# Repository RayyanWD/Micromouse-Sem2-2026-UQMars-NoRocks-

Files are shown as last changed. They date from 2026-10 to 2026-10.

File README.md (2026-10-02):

# Micromouse-Sem2-2026-UQMars-NoRocks-

# NO ROCKS ? – UQ Micromouse 2026

An autonomous micromouse built for the UQ Micromouse competition (4 October 2026).
It explores a 9×9 maze using a flood-fill algorithm, maps the walls as it goes,
and uses that saved map for faster runs to the centre.

**Team:** Rayyan Dewangga and Gordon Tam

**Video:** [YouTube / Google Drive link]
**Design document:** [docs/Design_Document.pdf](docs/Design_Document.pdf)
**Budget:** $180.17 AUD of $1,500 – see [docs/Micromouse_Budget.xlsx](docs/Micromouse_Budget.xlsx)

---

## Hardware

| Part | Purpose |
|---|---|
| ESP32-32U dev board | Main controller |
| 2× N20 motors with encoders (30:1, 7 PPR) | Drive + distance measurement |
| Pololu 32 mm wheels | Traction |
| DFRobot TB6612FNG motor driver (DRI0044) | Drives both motors |
| 3× VL53L0X time-of-flight sensors | Front, left and right wall detection |
| TCS34725 colour sensor | Floor / tile detection |
| MPU-6500 gyro | Mounted for future turn correction |
| MP1584EN buck converter | Battery → 3.3 V logic supply |
| 6×AA battery pack + rocker switch | Power |
| 3D-printed PLA chassis | Single flat deck, under 16 × 16 × 8 cm |

## Wiring summary

| Connection | ESP32 pin |
|---|---|
| Left motor PWM / DIR | GPIO 25 / 26 |
| Right motor PWM / DIR | GPIO 27 / 13 |
| Left encoder A / B | GPIO 34 / 35 |
| Right encoder A / B | GPIO 36 (VP) / 39 (VN) |
| ToF sensors SDA / SCL (I2C bus 1) | GPIO 21 / 22 |
| ToF XSHUT front / left / right | GPIO 16 / 17 / 18 |
| Colour sensor SDA / SCL (I2C bus 2) | GPIO 32 / 33 |
| Start / mode button | GPIO 0 (on-board BOOT) |
| Status LED | GPIO 2 (on-board) |

Power: battery → switch → motor driver VM and buck converter IN+.
Buck converter OUT+ (3.3 V) → ESP32 3V3, driver VCC, all sensors and encoders.
All grounds are common. Full diagram: [electronics/wiring.png](electronics/wiring.png)

## Software

`code/micromouse/micromouse.ino` – a single Arduino sketch for the ESP32.

- **Flood-fill search:** at every cell the mouse reads its walls, updates the map,
  recomputes distances to the centre and moves to the lowest-distance neighbour.
- **Map saved to flash**, so later runs use the known map for faster, straighter paths.
- **Wall centring** using the side ToF sensors, with encoder-based straight-line
  correction where there are no walls.
- **Colour sensor** reads the floor and can optionally treat a marked tile as the goal.

### Modes (BOOT button: short press = next mode, hold ~1 s = start)
The blue LED blinks the mode number.

1. **Explore** – flood-fill search to the centre, then back to start
2. **Speed run** – fastest known path using the saved map
3. **Sensors** – live ToF, colour and encoder readings over Serial (calibration)
4. **Test** – motor direction check, one cell straight, four 90° turns (calibration)
5. **Clear map** – wipe the saved maze

## Building and uploading

1. Install [Arduino IDE](https://www.arduino.cc/en/software) and the **esp32** board package.
2. Install the libraries **VL53L0X** (Pololu) and **Adafruit TCS34725** from Library Manager.
3. Open `code/micromouse/micromouse.ino`, select **ESP32 Dev Module**, and upload.
4. Open Serial Monitor at **115200 baud** to see sensor status and debug output.

Calibration values (wheel size, turn scale, wall thresholds, motor speeds)
are all in the `CALIBRATION` section at the top of the sketch.

## Repository structure

```
code/           Arduino source
docs/           Design document, budget spreadsheet, receipts
cad/            Chassis STL/STEP files
electronics/    Wiring diagram
media/          Photos and video link
```

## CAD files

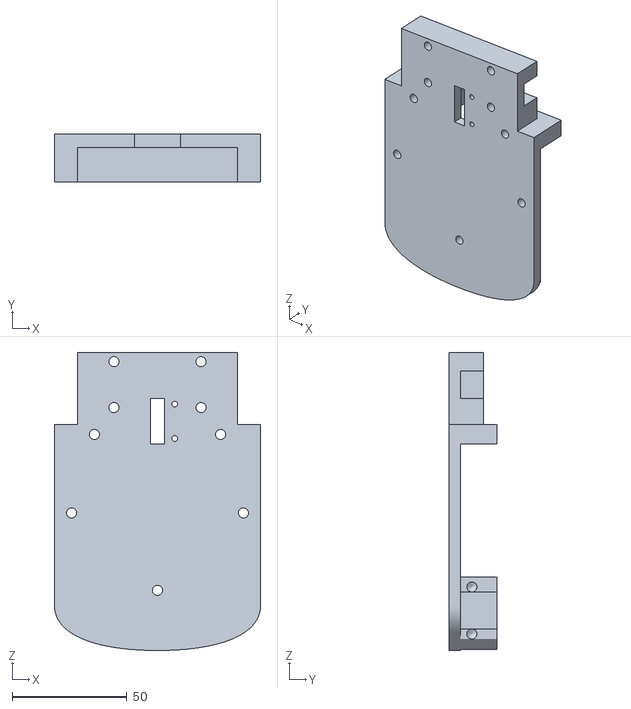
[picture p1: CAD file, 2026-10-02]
CAD/Base.stl
90.0 x 21.0 x 130.0

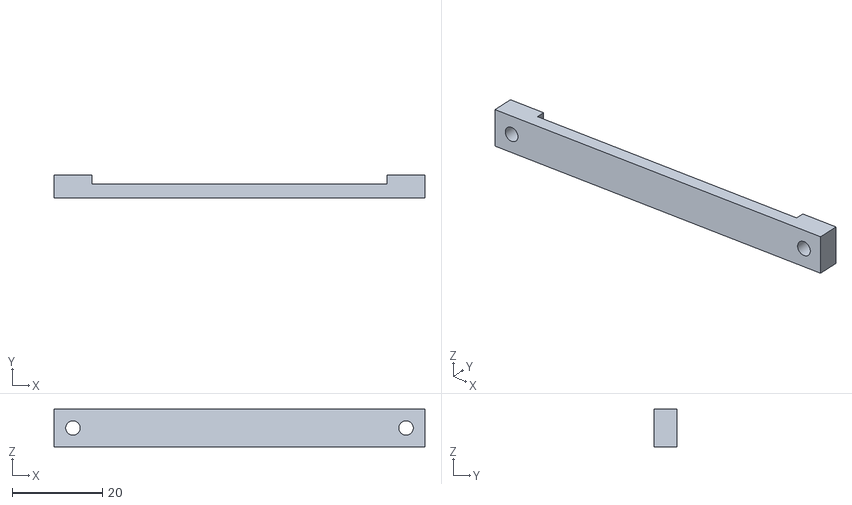
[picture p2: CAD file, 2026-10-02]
CAD/Clamp Strip.stl
82.4 x 5.00 x 8.40

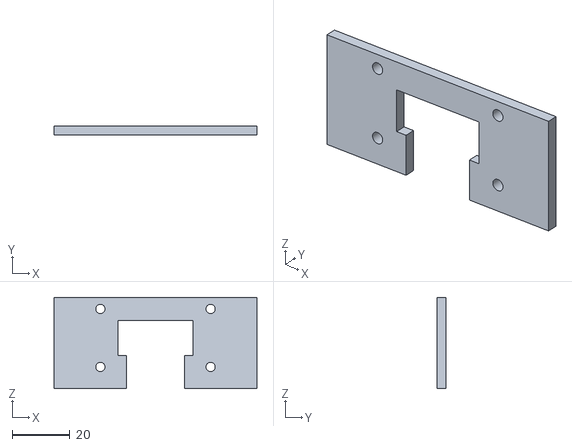
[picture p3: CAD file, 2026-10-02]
CAD/Top Deck.stl
70.0 x 3.00 x 31.5

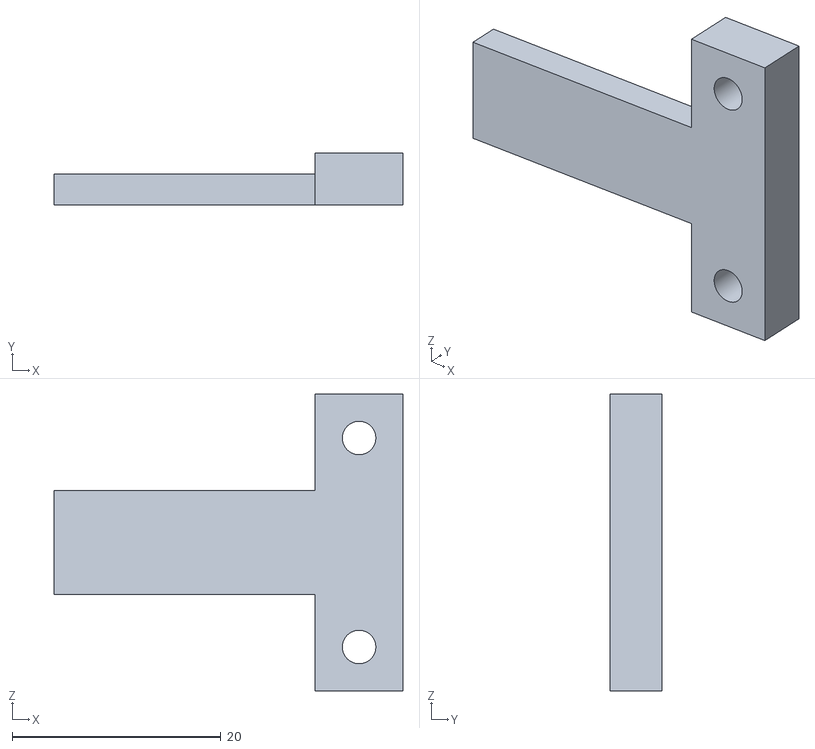
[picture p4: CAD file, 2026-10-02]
CAD/Small Clap.stl
33.4 x 5.00 x 28.4

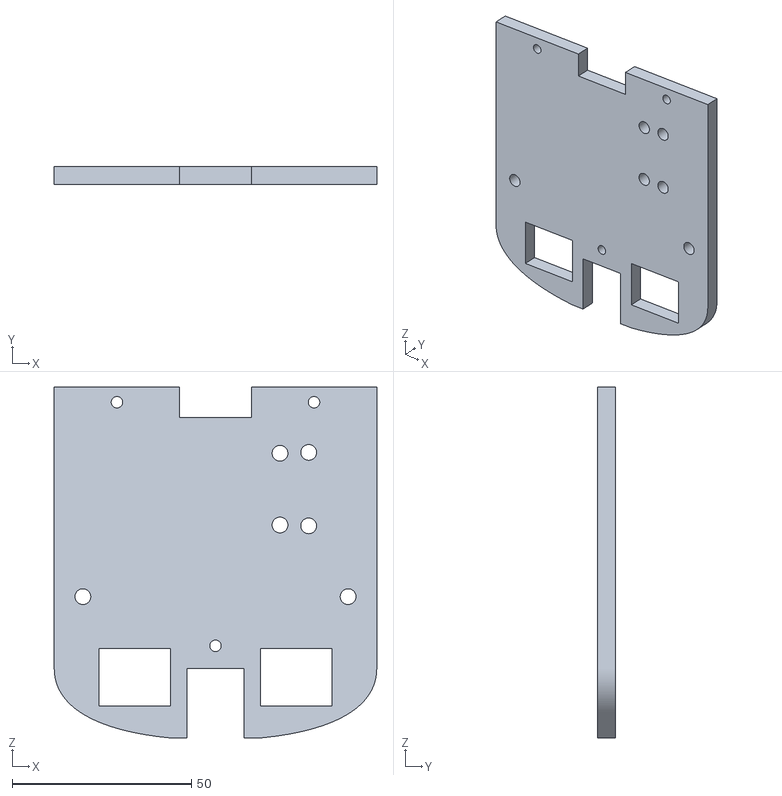
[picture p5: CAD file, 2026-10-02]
CAD/Mount Plate.stl
90.0 x 5.00 x 97.9

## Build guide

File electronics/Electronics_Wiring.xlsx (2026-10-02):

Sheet: Connections
No Rocks – wiring list (every connection)
From part | From pin | Wire colour | To part | To pin | Net | Notes
6×AA battery tray | + (red) | Red | Rocker switch | Terminal 1 | VBAT | Before switch
Rocker switch | Terminal 2 | Red | Splitter → TB6612FNG | VM (+12V) | VBAT | Battery voltage – never on VCC
Rocker switch | Terminal 2 | Red | Splitter → MP1584EN buck | IN+ | VBAT
6×AA battery tray | − (black) | Black | Ground harness (tail) | — | GND
MP1584EN buck | IN− | Black | Ground harness | — | GND | Two legs used, either is fine
MP1584EN buck | OUT− | Black | Ground harness | — | GND | Same ground as IN− on MP1584
MP1584EN buck | OUT+ (pin 1) | Red | 3.3 V splitter A (tail) | — | 3V3 | Set buck to 3.3–3.45 V before connecting
MP1584EN buck | OUT+ (pin 2) | Red | 3.3 V splitter B (tail) | — | 3V3
3.3 V splitter A | Leg | Red | ESP32 | 3V3 | 3V3
3.3 V splitter A | Leg | Red | TB6612FNG | VCC | 3V3 | Logic supply
3.3 V splitter A | Leg | Yellow | Left N20 motor | Yellow (enc VCC) | 3V3
3.3 V splitter A | Leg | Yellow | Right N20 motor | Yellow (enc VCC) | 3V3
3.3 V splitter B | Leg | Red | VL53L0X front | VIN | 3V3
3.3 V splitter B | Leg | Red | VL53L0X left | VIN | 3V3
3.3 V splitter B | Leg | Red | VL53L0X right | VIN | 3V3
3.3 V splitter B | Leg | Red | TCS34725 colour | VIN | 3V3
3.3 V splitter B | Leg | Red | MPU-6500 gyro | VCC | 3V3 | Optional
Ground harness | Leg | Black | ESP32 | GND (×2 pins) | GND | One per harness
Ground harness | Leg | Black | TB6612FNG | GND (×2) | GND
Ground harness | Leg | Blue | Left N20 motor | Blue (GND) | GND
Ground harness | Leg | Blue | Right N20 motor | Blue (GND) | GND
Ground harness | Leg | Black | VL53L0X front / left / right | GND | GND
Ground harness | Leg | Black | TCS34725 colour | GND | GND
Ground harness | Leg | Black | MPU-6500 gyro | GND | GND
ESP32 | GPIO25 | Signal | TB6612FNG | PWM1 | PWM_L | Left motor speed
ESP32 | GPIO26 | Signal | TB6612FNG | DIR1 | DIR_L | Left motor direction
ESP32 | GPIO27 | Signal | TB6612FNG | PWM2 | PWM_R | Right motor speed
ESP32 | GPIO13 | Signal | TB6612FNG | DIR2 | DIR_R | Right motor direction
TB6612FNG | M1+ | Red | Left N20 motor | Red (M+) | ML+
TB6612FNG | M1− | Black | Left N20 motor | Black (M−) | ML- | Not ground
TB6612FNG | M2+ | Red | Right N20 motor | Red (M+) | MR+
TB6612FNG | M2− | Black | Right N20 motor | Black (M−) | MR- | Not ground
Left N20 motor | Green (enc A) | Green | ESP32 | GPIO34 | ENC_LA | Input-only pin
Left N20 motor | White (enc B) | White | ESP32 | GPIO35 | ENC_LB | Input-only pin
Right N20 motor | Green (enc A) | Green | ESP32 | GPIO36 (VP) | ENC_RA | Input-only pin
Right N20 motor | White (enc B) | White | ESP32 | GPIO39 (VN) | ENC_RB | Input-only pin
I2C SDA splitter (blue) | Tail | Blue | ESP32 | GPIO21 | SDA1
I2C SDA splitter (blue) | Legs | Blue | VL53L0X ×3 + MPU-6500 | SDA / SDA/SDI | SDA1
I2C SCL splitter (brown) | Tail | Brown | ESP32 | GPIO22 | SCL1
I2C SCL splitter (brown) | Legs | Brown | VL53L0X ×3 + MPU-6500 | SCL / SCL/SCLK | SCL1
ESP32 | GPIO16 | Signal | VL53L0X front | XSHUT | XSHUT_F | Code sets address 0x30
ESP32 | GPIO17 | Signal | VL53L0X left | XSHUT | XSHUT_L | Code sets address 0x31
ESP32 | GPIO18 | Signal | VL53L0X right | XSHUT | XSHUT_R | Code sets address 0x32
ESP32 | GPIO32 | Signal | TCS34725 colour | SDA | SDA2 | Own I2C bus (Wire1)
ESP32 | GPIO33 | Signal | TCS34725 colour | SCL | SCL2 | Own I2C bus (Wire1)
TCS34725 colour | LED / INT / 3V3 out | — | Not connected | — | NC | LED left on

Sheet: ESP32 pins
No Rocks – ESP32 pin map (matches micromouse.ino)
ESP32 pin | Function | Net | Connected to | Name in code | Notes
3V3 | Power in | 3V3 | Buck OUT+ via splitter A
GND | Ground | GND | Ground harness (×2)
GPIO25 | PWM out | PWM_L | TB6612FNG PWM1 | L_PWM
GPIO26 | Digital out | DIR_L | TB6612FNG DIR1 | L_DIR
GPIO27 | PWM out | PWM_R | TB6612FNG PWM2 | R_PWM
GPIO13 | Digital out | DIR_R | TB6612FNG DIR2 | R_DIR
GPIO34 | Input (interrupt) | ENC_LA | Left motor green | L_ENC_A | Input-only, no pull-up
GPIO35 | Input | ENC_LB | Left motor white | L_ENC_B | Input-only, no pull-up
GPIO36 (VP) | Input (interrupt) | ENC_RA | Right motor green | R_ENC_A | Input-only, no pull-up
GPIO39 (VN) | Input | ENC_RB | Right motor white | R_ENC_B | Input-only, no pull-up
GPIO21 | I2C SDA (bus 1) | SDA1 | 3× VL53L0X, MPU-6500 | I2C1_SDA
GPIO22 | I2C SCL (bus 1) | SCL1 | 3× VL53L0X, MPU-6500 | I2C1_SCL
GPIO16 | Digital out | XSHUT_F | Front ToF XSHUT | XSHUT_F
GPIO17 | Digital out | XSHUT_L | Left ToF XSHUT | XSHUT_L
GPIO18 | Digital out | XSHUT_R | Right ToF XSHUT | XSHUT_R
GPIO32 | I2C SDA (bus 2) | SDA2 | TCS34725 | I2C2_SDA
GPIO33 | I2C SCL (bus 2) | SCL2 | TCS34725 | I2C2_SCL
GPIO0 | Input (pull-up) | — | On-board BOOT button | BTN_PIN | Short press = next mode, hold = start
GPIO2 | Digital out | — | On-board blue LED | LED_PIN | Blinks mode number

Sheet: Power
No Rocks – power rails
Rail | Voltage | Feeds
6×AA battery | 7.2 V (NiMH) – 9 V (alkaline) | Rocker switch → VBAT
VBAT | Battery voltage | TB6612FNG VM (motor power, max 12 V), MP1584EN IN+
MP1584EN OUT+ | Measured 3.45 V (lowest setting reached) | ESP32 3V3, TB6612 VCC, ToF ×3, colour sensor, gyro, encoders
GND | Common | Every part shares one ground

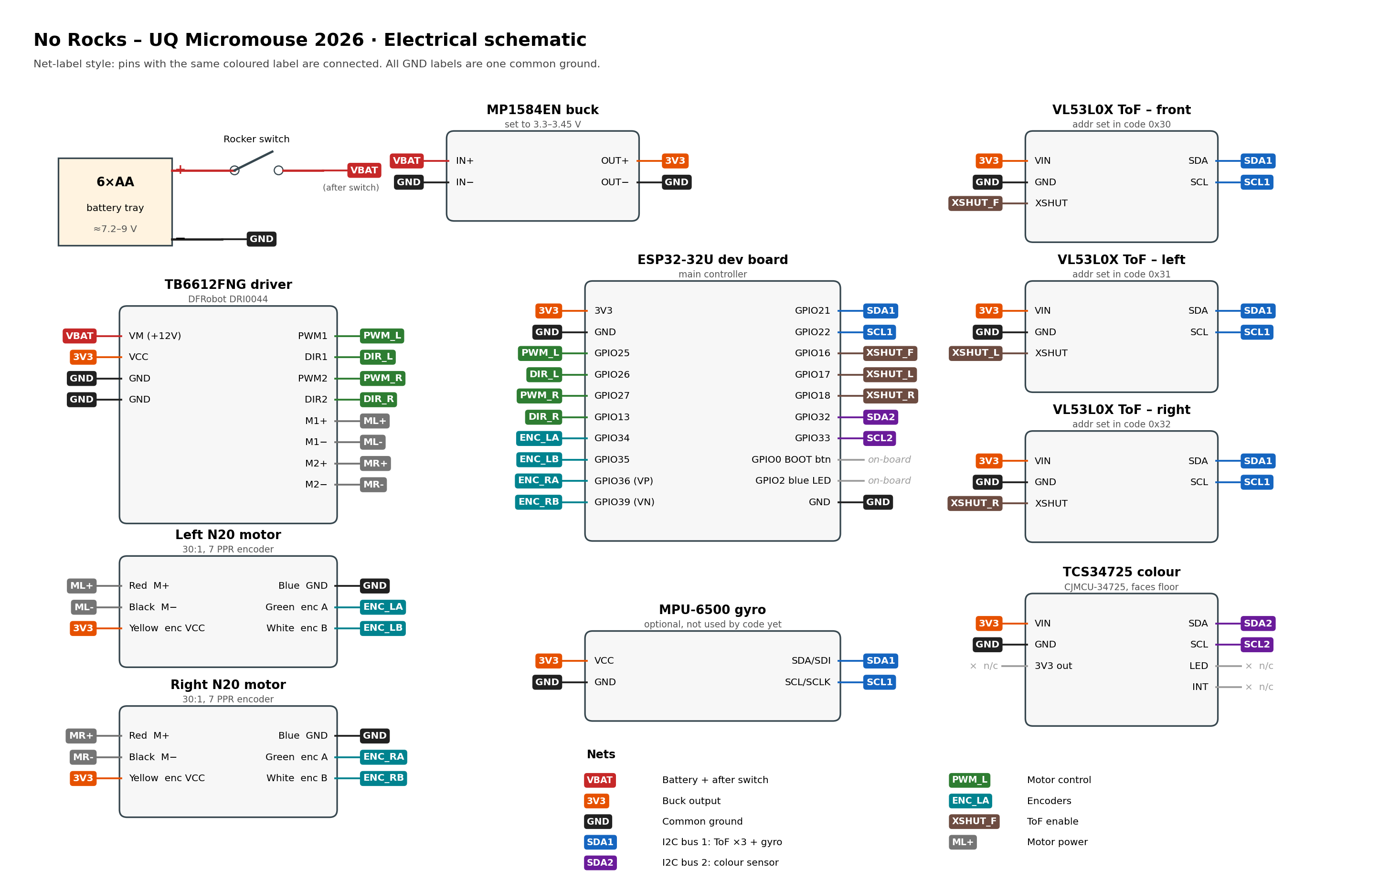
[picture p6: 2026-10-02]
electronics/wiring.png

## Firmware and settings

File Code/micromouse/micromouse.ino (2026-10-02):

/*
  UQ Micromouse 2026 – ESP32 firmware
  -----------------------------------
  Hardware (matches the wiring list):
    Motor driver  DIR/PWM type (pins VCC GND DIR2 PWM2 PWM1 DIR1)
                  PWM1 25, DIR1 26 (left)   PWM2 27, DIR2 13 (right)
    Encoders      left A/B 34/35          right A/B 36/39
    I2C bus 1     SDA 21, SCL 22  -> 3x VL53L0X
    VL53L0X XSHUT front 16, left 17, right 18
    I2C bus 2     SDA 32, SCL 33  -> colour sensor (TCS34725)
    Button        GPIO 0 (the BOOT button on the ESP32 board)
    Status LED    GPIO 2 (the blue LED on the ESP32 board)

  Libraries (Arduino IDE > Library Manager):
    - "VL53L0X" by Pololu
    - "Adafruit TCS34725"
  Board: "ESP32 Dev Module" (esp32 core 2.x or 3.x both work)

  No display: status goes to the blue LED and to Serial Monitor (115200 baud).
    LED blinks the mode number: 1 = Explore, 2 = Speed run, 3 = Sensors,
    4 = Test, 5 = Clear map. Solid on = running. Fast flicker = goal reached.

  Using it:
    Short press BOOT = next mode, long press (hold ~1 s, then release) = start.
    Modes:
      Explore   – flood-fill search to the centre, maps as it goes, saves map
      Speed run – uses the saved map for the fastest known path
      Sensors   – live ToF / colour / encoder readings (for calibration)
      Test      – checks motor direction, 1 cell straight, 4 right turns
      Clear map – wipe the saved map (do this once the real maze is revealed!)
    Press BOOT during any run to abort.

  Calibration values are all in the CALIBRATION section below. Changing those
  between runs is calibration, not a change to the navigation algorithm.
*/

#include <Wire.h>
#include <VL53L0X.h>
#include <Adafruit_TCS34725.h>
#include <Preferences.h>

#ifndef ESP_ARDUINO_VERSION_MAJOR
#define ESP_ARDUINO_VERSION_MAJOR 2
#endif

// ======================= PINS =======================
#define L_PWM    25   // driver PWM1
#define L_DIR    26   // driver DIR1
#define R_PWM    27   // driver PWM2
#define R_DIR    13   // driver DIR2
#define L_ENC_A  34
#define L_ENC_B  35
#define R_ENC_A  36
#define R_ENC_B  39
#define XSHUT_F  16
#define XSHUT_L  17
#define XSHUT_R  18
#define I2C1_SDA 21
#define I2C1_SCL 22
#define I2C2_SDA 32
#define I2C2_SCL 33
#define BTN_PIN  0
#define LED_PIN  2

// ======================= CALIBRATION =======================
// Set to 0 if your motors have no encoders (falls back to timed moves).
#define USE_ENCODERS 1

// Motors: BJ-N20-12-1000 (12 V, 1:30 gearbox, 7 PPR encoder)
//   Blue=GND  Green=Enc A  White=Enc B  Yellow=3.3V  Black=Motor-  Red=Motor+
const float WHEEL_DIA_MM         = 32.0;   // 32 mm wheels with silicone tyres
const float COUNTS_PER_WHEEL_REV = 420.0;  // 7 pulses x 2 edges x 30:1 gearbox
const float TRACK_MM             = 90.0;   // MEASURE: distance between the two wheel centres
const float TURN_SCALE           = 1.00;   // >1 if turns come up short, <1 if they overshoot
const float CELL_MM              = 180.0;

// Flip to -1 if a wheel spins the wrong way / an encoder counts backwards
const int L_MOTOR_DIR = 1,  R_MOTOR_DIR = 1;
const int L_ENC_DIR   = 1,  R_ENC_DIR   = 1;

// Timed fallback (only used when USE_ENCODERS is 0)
const int MS_PER_CELL = 900;   // at EXPLORE_PWM
const int MS_PER_90   = 350;   // at TURN_PWM

// Motor power (0-255). The N20s are 12 V motors on a 6-9 V pack, so full PWM is safe.
const int PWM_FREQ    = 10000;
const int MAX_PWM     = 255;
const int MIN_PWM     = 80;    // lowest value that still moves the mouse
const int EXPLORE_PWM = 150;
const int SPEED_PWM   = 210;
const int TURN_PWM    = 130;

// Wall sensing (mm, as read by each ToF). Use Sensors mode to measure.
const int FRONT_WALL_MM    = 120; // closer than this = wall ahead
const int FRONT_CENTRED_MM = 35;  // front reading when centred in a cell facing a wall
const int SIDE_WALL_MM     = 110; // closer than this = wall at the side
const int SIDE_CENTRED_MM  = 40;  // side reading when centred in a cell
const int TOF_OFFSET_F = 0, TOF_OFFSET_L = 0, TOF_OFFSET_R = 0;

// Steering gains
const float K_WALL = 1.2;  // centring between walls
const float K_ENC  = 2.0;  // keep straight from encoders when no walls

// Colour sensor
const bool  COLOUR_GOAL   = false; // true = a coloured/bright tile also counts as the goal
const float COLOUR_FACTOR = 2.0;   // tile counts as "marked" if this many times brighter than the floor

const bool RETURN_TO_START = true; // after reaching the centre, explore back to start (maps more)

// ======================= MAZE =======================
const int N = 9;
const int GOAL_X = 4, GOAL_Y = 4;
const int DX[4] = {0, 1, 0, -1};   // 0=N 1=E 2=S 3=W
const int DY[4] = {1, 0, -1, 0};

uint8_t walls[N][N];   // bit d set = wall on side d
uint8_t known[N][N];   // bit d set = side d has been seen
uint8_t distv[N][N];
int mx = 0, my = 0, hd = 0;   // position + heading. Start = (0,0) facing N, outer walls left & behind.

// ======================= OBJECTS =======================
VL53L0X tofF, tofL, tofR;
Adafruit_TCS34725 tcs(TCS34725_INTEGRATIONTIME_24MS, TCS34725_GAIN_16X);
Preferences prefs;

int  distF = 2000, distL = 2000, distR = 2000;
bool tofOK[3] = {false, false, false};
bool colourOK = false;
uint16_t floorClear = 0;
uint16_t cr, cg, cb, cc;

volatile long rawL = 0, rawR = 0;
volatile bool aborted = false;

// ======================= PWM / MOTORS =======================
#if ESP_ARDUINO_VERSION_MAJOR < 3
int pwmChan[40];
int nextChan = 0;
#endif

void pwmInit(int pin) {
#if ESP_ARDUINO_VERSION_MAJOR >= 3
  ledcAttach(pin, PWM_FREQ, 8);
#else
  pwmChan[pin] = nextChan;
  ledcSetup(nextChan, PWM_FREQ, 8);
  ledcAttachPin(pin, nextChan);
  nextChan++;
#endif
}

void pwmOut(int pin, int duty) {
#if ESP_ARDUINO_VERSION_MAJOR >= 3
  ledcWrite(pin, duty);
#else
  ledcWrite(pwmChan[pin], duty);
#endif
}

// DIR/PWM driver: DIR pin sets direction, PWM pin sets speed
void motorRaw(int pwmPin, int dirPin, int pwm) {
  pwm = constrain(pwm, -MAX_PWM, MAX_PWM);
  digitalWrite(dirPin, pwm >= 0 ? HIGH : LOW);
  pwmOut(pwmPin, abs(pwm));
}

int lastL = 0, lastR = 0;

void setMotors(int l, int r) {
  lastL = l; lastR = r;
  motorRaw(L_PWM, L_DIR, l * L_MOTOR_DIR);
  motorRaw(R_PWM, R_DIR, r * R_MOTOR_DIR);
}

// Short reverse pulse to stop quickly, then off
void brake() {
  int l = lastL, r = lastR;
  setMotors(l > 0 ? -60 : (l < 0 ? 60 : 0), r > 0 ? -60 : (r < 0 ? 60 : 0));
  delay(25);
  setMotors(0, 0);
  delay(35);
}

// ======================= ENCODERS =======================
void IRAM_ATTR isrL() { if (digitalRead(L_ENC_A) == digitalRead(L_ENC_B)) rawL--; else rawL++; }
void IRAM_ATTR isrR() { if (digitalRead(R_ENC_A) == digitalRead(R_ENC_B)) rawR--; else rawR++; }
long encL() { return rawL * L_ENC_DIR; }
long encR() { return rawR * R_ENC_DIR; }
long encDiff() { return encL() - encR(); }
void encReset() { noInterrupts(); rawL = 0; rawR = 0; interrupts(); }
float countsPerMm() { return COUNTS_PER_WHEEL_REV / (PI * WHEEL_DIA_MM); }

// ======================= ABORT / BUTTON =======================
bool checkAbort() {
  if (!aborted && digitalRead(BTN_PIN) == LOW) { aborted = true; setMotors(0, 0); }
  return aborted;
}

// 0 = nothing, 1 = short press, 2 = long press
int readButton() {
  if (digitalRead(BTN_PIN) == HIGH) return 0;
  unsigned long t0 = millis();
  while (digitalRead(BTN_PIN) == LOW) delay(5);
  delay(30);
  return (millis() - t0 > 800) ? 2 : 1;
}

void waitRelease() { while (digitalRead(BTN_PIN) == LOW) delay(5); delay(50); }

// ======================= STATUS (Serial + LED) =======================
void show(const char* a, const char* b = "", const char* c = "", const char* d = "") {
  Serial.printf("%s | %s | %s | %s\n", a, b, c, d);
}

void led(bool on) { digitalWrite(LED_PIN, on ? HIGH : LOW); }

void blinkCount(int n) {
  for (int i = 0; i < n; i++) { led(true); delay(180); led(false); delay(180); }
}

void flicker(int ms) {
  unsigned long t0 = millis();
  while (millis() - t0 < (unsigned long)ms) { led(true); delay(50); led(false); delay(50); }
}

// ======================= TOF SENSORS =======================
bool bringUpToF(int pin, VL53L0X &s, uint8_t addr) {
  digitalWrite(pin, HIGH);
  delay(10);
  s.setTimeout(100);
  if (!s.init()) return false;
  s.setAddress(addr);
  s.setMeasurementTimingBudget(20000);
  s.startContinuous(0);
  return true;
}

void initToF() {
  tofOK[0] = bringUpToF(XSHUT_F, tofF, 0x30);
  tofOK[1] = bringUpToF(XSHUT_L, tofL, 0x31);
  tofOK[2] = bringUpToF(XSHUT_R, tofR, 0x32);
}

// Non-blocking read: returns true if a new value arrived
bool pollToF(VL53L0X &s, int &out, int offset) {
  if ((s.readReg(VL53L0X::RESULT_INTERRUPT_STATUS) & 0x07) == 0) return false;
  uint16_t r = s.readReg16Bit(VL53L0X::RESULT_RANGE_STATUS + 10);
  s.writeReg(VL53L0X::SYSTEM_INTERRUPT_CLEAR, 0x01);
  out = (r == 0 || r >= 2000) ? 2000 : (int)r + offset;
  return true;
}

void updateToF() {
  if (tofOK[0]) pollToF(tofF, distF, TOF_OFFSET_F);
  if (tofOK[1]) pollToF(tofL, distL, TOF_OFFSET_L);
  if (tofOK[2]) pollToF(tofR, distR, TOF_OFFSET_R);
}

void settleToF(int ms) {
  unsigned long t0 = millis();
  while (millis() - t0 < (unsigned long)ms) { updateToF(); delay(3); }
}

// ======================= COLOUR SENSOR =======================
void readColour() { if (colourOK) tcs.getRawData(&cr, &cg, &cb, &cc); }

void calibrateFloor() {
  if (!colourOK) return;
  uint32_t sum = 0;
  for (int i = 0; i < 4; i++) { readColour(); sum += cc; }
  floorClear = sum / 4;
}

bool onMarkedTile() {
  if (!colourOK || floorClear == 0) return false;
  readColour();
  return cc > floorClear * COLOUR_FACTOR && cc > floorClear + 40;
}

const char* colourName() {
  if (!colourOK) return "none";
  readColour();
  if (floorClear && cc < floorClear * COLOUR_FACTOR) return "floor";
  uint16_t mxc = max(cr, max(cg, cb)), mnc = min(cr, min(cg, cb));
  if (mxc < mnc * 1.3) return "white";
  if (mxc == cr) return "red";
  if (mxc == cg) return "green";
  return "blue";
}

// ======================= MAZE LOGIC =======================
bool inMaze(int x, int y) { return x >= 0 && y >= 0 && x < N && y < N; }

void setWall(int x, int y, int d, bool w) {
  int nx = x + DX[d], ny = y + DY[d];
  if (!inMaze(nx, ny)) w = true;            // never "remove" an outer wall
  known[x][y] |= (1 << d);
  if (w) walls[x][y] |= (1 << d); else walls[x][y] &= ~(1 << d);
  if (inMaze(nx, ny)) {
    int od = (d + 2) % 4;
    known[nx][ny] |= (1 << od);
    if (w) walls[nx][ny] |= (1 << od); else walls[nx][ny] &= ~(1 << od);
  }
}

void mazeReset() {
  memset(walls, 0, sizeof(walls));
  memset(known, 0, sizeof(known));
  for (int i = 0; i < N; i++) {
    setWall(i, 0, 2, true);
    setWall(i, N - 1, 0, true);
    setWall(0, i, 3, true);
    setWall(N - 1, i, 1, true);
  }
}

bool canGo(int x, int y, int d, bool unknownBlocked) {
  if (walls[x][y] & (1 << d)) return false;
  if (unknownBlocked && !(known[x][y] & (1 << d))) return false;
  return inMaze(x + DX[d], y + DY[d]);
}

void flood(bool toStart, bool unknownBlocked) {
  memset(distv, 255, sizeof(distv));
  uint8_t qx[N * N], qy[N * N];
  int h = 0, t = 0;
  int tx = toStart ? 0 : GOAL_X, ty = toStart ? 0 : GOAL_Y;
  distv[tx][ty] = 0; qx[t] = tx; qy[t] = ty; t++;
  while (h < t) {
    int x = qx[h], y = qy[h]; h++;
    for (int d = 0; d < 4; d++) {
      if (!canGo(x, y, d, unknownBlocked)) continue;
      int nx = x + DX[d], ny = y + DY[d];
      if (distv[nx][ny] == 255) { distv[nx][ny] = distv[x][y] + 1; qx[t] = nx; qy[t] = ny; t++; }
    }
  }
}

// Lowest-distance neighbour. Ties prefer straight, then right, left, back.
int bestDir(bool unknownBlocked) {
  const int order[4] = {0, 1, 3, 2};
  int best = -1, bd = 255;
  for (int k = 0; k < 4; k++) {
    int d = (hd + order[k]) % 4;
    if (!canGo(mx, my, d, unknownBlocked)) continue;
    int v = distv[mx + DX[d]][my + DY[d]];
    if (v < bd) { bd = v; best = d; }
  }
  return best;
}

int knownCells() {
  int n = 0;
  for (int x = 0; x < N; x++) for (int y = 0; y < N; y++) if (known[x][y] == 0x0F) n++;
  return n;
}

void saveMaze() {
  prefs.begin("mouse", false);
  prefs.putBytes("walls", walls, sizeof(walls));
  prefs.putBytes("known", known, sizeof(known));
  prefs.end();
}

void loadMaze() {
  mazeReset();
  prefs.begin("mouse", true);
  if (prefs.getBytesLength("walls") == sizeof(walls)) {
    prefs.getBytes("walls", walls, sizeof(walls));
    prefs.getBytes("known", known, sizeof(known));
  }
  prefs.end();
}

void senseWalls() {
  settleToF(70);
  setWall(mx, my, hd,           distF < FRONT_WALL_MM);
  setWall(mx, my, (hd + 3) % 4, distL < SIDE_WALL_MM);
  setWall(mx, my, (hd + 1) % 4, distR < SIDE_WALL_MM);
}

// ======================= MOTION =======================
// Drives forward up to mm. Stops early at a front wall. Returns mm actually travelled.
float driveStraight(float mm, int topPwm) {
  if (aborted) return 0;
  encReset();
  long diffHold = 0;
  float done = 0;
  unsigned long t0 = millis();
  unsigned long tTotal = (unsigned long)(mm / CELL_MM * MS_PER_CELL * (float)EXPLORE_PWM / topPwm);

  while (true) {
    if (checkAbort()) return done;
    updateToF();

#if USE_ENCODERS
    done = ((encL() + encR()) / 2) / countsPerMm();
#else
    done = mm * (float)(millis() - t0) / tTotal;
#endif
    float remaining = mm - done;
    if (remaining <= 0) break;
    if (distF <= FRONT_CENTRED_MM) break;

    // speed profile: ramp up, ramp down
    int pwm = topPwm;
    pwm = min(pwm, (int)(MIN_PWM + done * 3));
    pwm = min(pwm, (int)(MIN_PWM + remaining * 2));
    pwm = max(pwm, MIN_PWM);

    // steering
    bool lw = distL < SIDE_WALL_MM, rw = distR < SIDE_WALL_MM;
    float corr = 0;
    if (lw && rw)  { corr = K_WALL * (distL - distR) / 2.0; diffHold = encDiff(); }
    else if (lw)   { corr = K_WALL * (distL - SIDE_CENTRED_MM); diffHold = encDiff(); }
    else if (rw)   { corr = K_WALL * (SIDE_CENTRED_MM - distR); diffHold = encDiff(); }
#if USE_ENCODERS
    else           { corr = K_ENC * (encDiff() - diffHold); }
#endif
    corr = constrain(corr, -40, 40);
    setMotors(pwm - (int)corr, pwm + (int)corr);
    delay(2);
  }
  brake();
  return done;
}

// Square up to a wall in front using the front ToF
void alignFront() {
  unsigned long t0 = millis();
  while (millis() - t0 < 500) {
    if (checkAbort()) return;
    updateToF();
    int e = distF - FRONT_CENTRED_MM;
    if (abs(e) <= 3) break;
    int p = constrain(e * 3, -90, 90);
    int floorP = MIN_PWM - 10;
    if (abs(p) < floorP) p = (p > 0) ? floorP : -floorP;
    setMotors(p, p);
    delay(5);
  }
  brake();
}

// q = +1 right 90, -1 left 90, 2 = 180
void turnQuarter(int q) {
  if (aborted || q == 0) return;
  float deg = q * 90.0;
  int dir = deg > 0 ? 1 : -1;
  encReset();
#if USE_ENCODERS
  float arc = PI * TRACK_MM * fabs(deg) / 360.0 * TURN_SCALE;
  long target = (long)(arc * countsPerMm());
  while (true) {
    if (checkAbort()) return;
    long done = (labs(encL()) + labs(encR())) / 2;
    if (done >= target) break;
    long rem = target - done;
    int p = min(TURN_PWM, (int)(MIN_PWM + rem * 2));
    setMotors(dir * p, -dir * p);
    delay(2);
  }
#else
  unsigned long t = (unsigned long)(MS_PER_90 * fabs(deg) / 90.0 * TURN_SCALE);
  unsigned long t0 = millis();
  while (millis() - t0 < t) {
    if (checkAbort()) return;
    setMotors(dir * TURN_PWM, -dir * TURN_PWM);
    delay(2);
  }
#endif
  brake();
  delay(80);
}

void faceDir(int d) {
  int rel = (d - hd + 4) % 4;
  if (rel == 1) turnQuarter(1);
  else if (rel == 3) turnQuarter(-1);
  else if (rel == 2) turnQuarter(2);
  hd = d;
}

// Drive n cells in the current heading, update position. Returns cells moved.
int forwardCells(int n, int pwm) {
  float mm = driveStraight(n * CELL_MM, pwm);
  int moved = (int)(mm / CELL_MM + 0.5);
  if (moved > n) moved = n;
  if (moved == 0 && n > 0) setWall(mx, my, hd, true);   // blocked straight away = wall we missed
  mx += DX[hd] * moved;
  my += DY[hd] * moved;
  settleToF(30);
  if (distF < FRONT_WALL_MM) alignFront();
  return moved;
}

// ======================= SEARCH / RUNS =======================
bool atGoal(bool toStart) {
  if (toStart) return mx == 0 && my == 0;
  if (mx == GOAL_X && my == GOAL_Y) return true;
  return COLOUR_GOAL && onMarkedTile();
}

// Flood-fill exploration. Unknown walls are treated as open.
bool explore(bool toStart) {
  while (!aborted) {
    senseWalls();
    if (atGoal(toStart)) return true;
    flood(toStart, false);
    int d = bestDir(false);
    if (d < 0) return false;            // boxed in: no route
    faceDir(d);
    forwardCells(1, EXPLORE_PWM);
  }
  return false;
}

// Fast run on known cells only, merging straights. Falls back to exploring if the map has gaps.
bool speedRun() {
  while (!aborted) {
    if (atGoal(false)) return true;
    flood(false, true);
    if (distv[mx][my] == 255) return explore(false);
    int d = bestDir(true);
    if (d < 0) return explore(false);
    faceDir(d);
    int n = 1, x = mx + DX[d], y = my + DY[d];
    while (!(x == GOAL_X && y == GOAL_Y) && canGo(x, y, d, true)) {
      int nx = x + DX[d], ny = y + DY[d];
      if (distv[nx][ny] != distv[x][y] - 1) break;
      x = nx; y = ny; n++;
    }
    int moved = forwardCells(n, SPEED_PWM);
    if (moved < n) senseWalls();        // something unexpected: re-check walls
  }
  return false;
}

// ======================= MODES =======================
const char* MODES[] = {"Explore", "Speed run", "Sensors", "Test moves", "Clear map"};
const int NUM_MODES = 5;
int mode = 0;

void countdown() {
  for (int i = 2; i > 0; i--) {
    char b[20]; snprintf(b, sizeof(b), "Hands off... %d", i);
    show(MODES[mode], b);
    delay(700);
  }
}

void doRun(bool fast) {
  countdown();
  aborted = false;
  mx = 0; my = 0; hd = 0;
  calibrateFloor();
  led(true);
  unsigned long t0 = millis();
  bool ok = fast ? speedRun() : explore(false);
  unsigned long t = millis() - t0;
  setMotors(0, 0);
  led(false);
  saveMaze();
  if (ok) flicker(1500);

  char l2[24], l3[24];
  if (ok) {
    snprintf(l2, sizeof(l2), "Time %lu.%02lus", t / 1000, (t % 1000) / 10);
    snprintf(l3, sizeof(l3), "Cells known %d", knownCells());
    show("GOAL!", l2, l3, aborted ? "" : "Returning...");
    Serial.printf("Goal in %lu ms\n", t);
    if (RETURN_TO_START && !aborted) {
      delay(1000);
      explore(true);
      faceDir(0);
      setMotors(0, 0);
      saveMaze();
      show("GOAL!", l2, l3, "Back at start");
    }
  } else {
    snprintf(l2, sizeof(l2), "At cell %d,%d", mx, my);
    show(aborted ? "Aborted" : "No route found", l2, "Map saved", "Press to continue");
  }
  waitRelease();
  while (readButton() == 0) delay(10);
  aborted = false;
}

void sensorMode() {
  waitRelease();
  calibrateFloor();
  while (true) {
    updateToF();
    readColour();
    char a[24], b[24], c[24], d[24];
    snprintf(a, sizeof(a), "F%4d L%4d R%4d", distF, distL, distR);
    snprintf(b, sizeof(b), "r%u g%u b%u", cr, cg, cb);
    snprintf(c, sizeof(c), "c%u %s", cc, colourName());
    snprintf(d, sizeof(d), "encL%ld R%ld", encL(), encR());
    show(a, b, c, d);
    led(onMarkedTile());   // LED lights when the colour sensor sees a marked tile
    if (digitalRead(BTN_PIN) == LOW) { waitRelease(); return; }
    delay(100);
  }
}

void testMode() {
  countdown();
  aborted = false;
  show("Test", "Both wheels fwd?");
  setMotors(MIN_PWM + 20, MIN_PWM + 20);
  unsigned long t0 = millis();
  while (millis() - t0 < 600) { if (checkAbort()) break; delay(5); }
  brake();
  char b[24]; snprintf(b, sizeof(b), "encL%ld R%ld", encL(), encR());
  show("Test", b, "both should be +");
  delay(1500);
  if (!aborted) { show("Test", "1 cell straight"); driveStraight(CELL_MM, EXPLORE_PWM); delay(500); }
  for (int i = 0; i < 4 && !aborted; i++) { show("Test", "4 right turns", "should end facing", "the same way"); turnQuarter(1); delay(300); }
  setMotors(0, 0);
  show("Test done", "", "Press to continue");
  waitRelease();
  while (readButton() == 0) delay(10);
  aborted = false;
}

void runSelected() {
  switch (mode) {
    case 0: doRun(false); break;
    case 1: doRun(true); break;
    case 2: sensorMode(); break;
    case 3: testMode(); break;
    case 4: mazeReset(); saveMaze(); show("Map cleared"); delay(800); break;
  }
}

// ======================= SETUP / LOOP =======================
void setup() {
  Serial.begin(115200);

  pinMode(XSHUT_F, OUTPUT); digitalWrite(XSHUT_F, LOW);
  pinMode(XSHUT_L, OUTPUT); digitalWrite(XSHUT_L, LOW);
  pinMode(XSHUT_R, OUTPUT); digitalWrite(XSHUT_R, LOW);
  pinMode(BTN_PIN, INPUT_PULLUP);

  pinMode(L_DIR, OUTPUT); pinMode(R_DIR, OUTPUT);
  pwmInit(L_PWM); pwmInit(R_PWM);
  setMotors(0, 0);

#if USE_ENCODERS
  pinMode(L_ENC_A, INPUT); pinMode(L_ENC_B, INPUT);
  pinMode(R_ENC_A, INPUT); pinMode(R_ENC_B, INPUT);
  attachInterrupt(digitalPinToInterrupt(L_ENC_A), isrL, CHANGE);
  attachInterrupt(digitalPinToInterrupt(R_ENC_A), isrR, CHANGE);
#endif

  pinMode(LED_PIN, OUTPUT);
  led(false);

  Wire.begin(I2C1_SDA, I2C1_SCL);
  Wire.setClock(400000);
  show("Micromouse", "Starting...");
  delay(20);

  initToF();

  Wire1.begin(I2C2_SDA, I2C2_SCL);
  colourOK = tcs.begin(TCS34725_ADDRESS, &Wire1);

  loadMaze();
  Serial.printf("ToF F%d L%d R%d  colour %d  cells known %d\n",
                tofOK[0], tofOK[1], tofOK[2], colourOK, knownCells());
}
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
void loop() {
  if (menuDirty) { printMenu(); menuDirty = false; }
  menuBlink();

  int b = readButton();
  if (b == 1) { mode = (mode + 1) % NUM_MODES; menuDirty = true; led(false); delay(400); }
  else if (b == 2) { led(false); runSelected(); led(false); menuDirty = true; }
  delay(10);
}
